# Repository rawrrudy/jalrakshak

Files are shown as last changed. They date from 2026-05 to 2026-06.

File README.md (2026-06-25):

<p align="center">
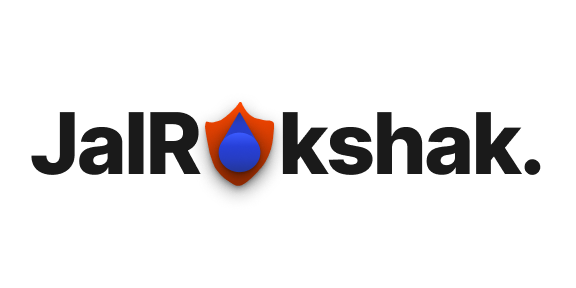
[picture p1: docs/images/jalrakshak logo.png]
  
</p>

<h1 align="center"> JalRakshak </h1>

<p align="center">
  Water Monitoring Device
</p>

<p align="center">
  An ESP-32 powered "floating" water monitoring device with pH, Temperature, TDS and Turbidity sensors!
</p>

# Index

#### [1) JalRakshak Zine](#jalrakshak-zine)
#### [2) What is JalRakshak?](#what-is-jalrakshak)
#### [3) Why was JalRakshak made?](#why-was-jalrakshak-made)
#### [4) Key Features](#key-features)
#### [5) PCB](#pcb)
#### [6) Images](#images)
#### [7) How to Build and Run?](#how-to-build-and-run)
#### [8) Credits](#credits)
#### [9) License](#license)

# JalRakshak Zine

<p align="center">
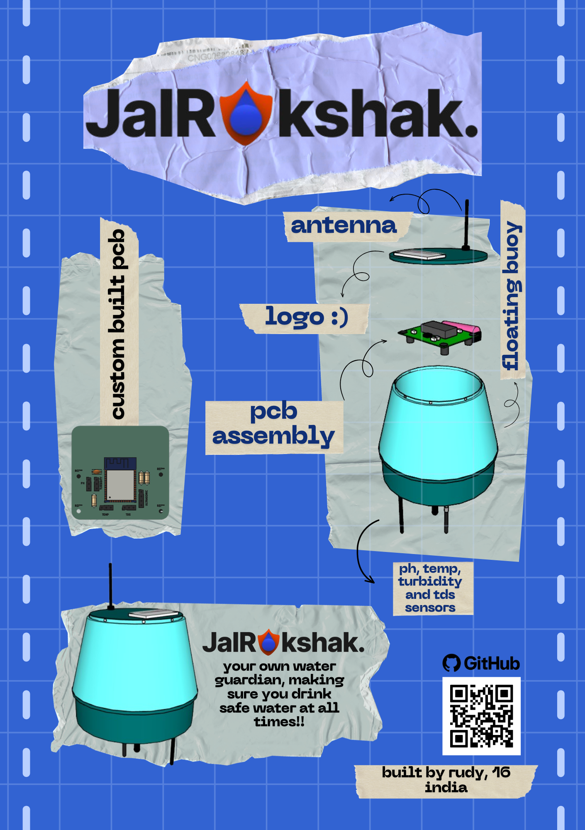
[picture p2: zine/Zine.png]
  
</p>

# What is JalRakshak?

JalRakshak is an ESP32 powered water quality monitoring device, that continously measures pH, TDS, Turbidity, Temperature and Water Level! It uses a custom built PCB and enclosure to help communities protect lakes, reservoirs and local water bodies.

<p align="center"> 
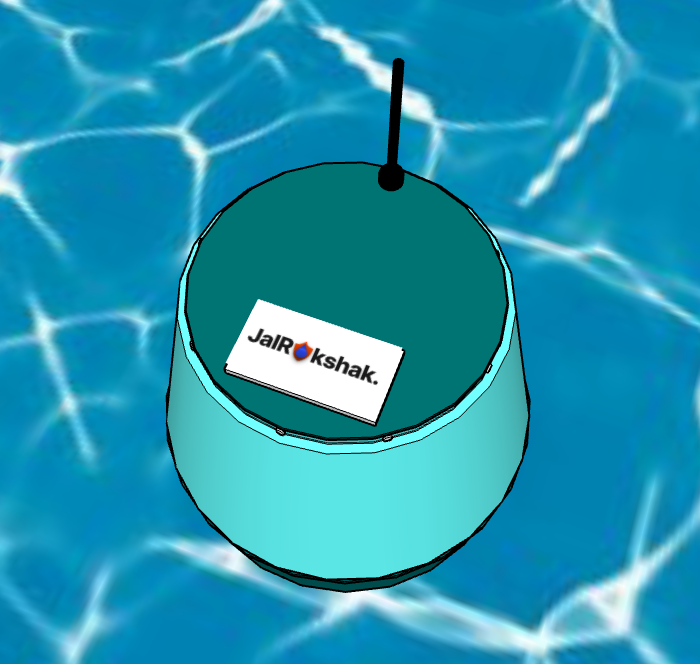
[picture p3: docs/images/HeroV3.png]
   
</p>

<p align="center">
 A basic 3D outline of JalRakshak V1
</p>

# Why was JalRakshak made?

Water pollution is one of the biggest challenges to the environment in recent days. Not only does it affect aquatic fauna, it can also cause significant damage to humans due to unhygenic conditions of water. This issue is widespread in rural areas, especially in the country I am from, India. To help combat this issue, even at a significantly smaller scale, JalRakshak was created. Attached is a link to a credible source which discusses the major problems caused due to water pollution - 

https://www.frontiersin.org/journals/environmental-science/articles/10.3389/fenvs.2022.880246/full

# Key Features

- ESP32 microcontroller with integrated Wi-Fi
- Analyses Temperature, TDS, Turbidity, pH and Water Level
- Sends an alert via email when safety threshold is exceeded
- Custom designed PCB for sensor integration
- DS18B20 waterproof temperature sensor
- DFRobot Gravity pH and TDS sensor
- SEN0189 turbidity sensing for water clarity check
- HC-SR04 ultrasonic water level measurement
- Custom CAD optimised to float on water

# PCB
<p align="center">
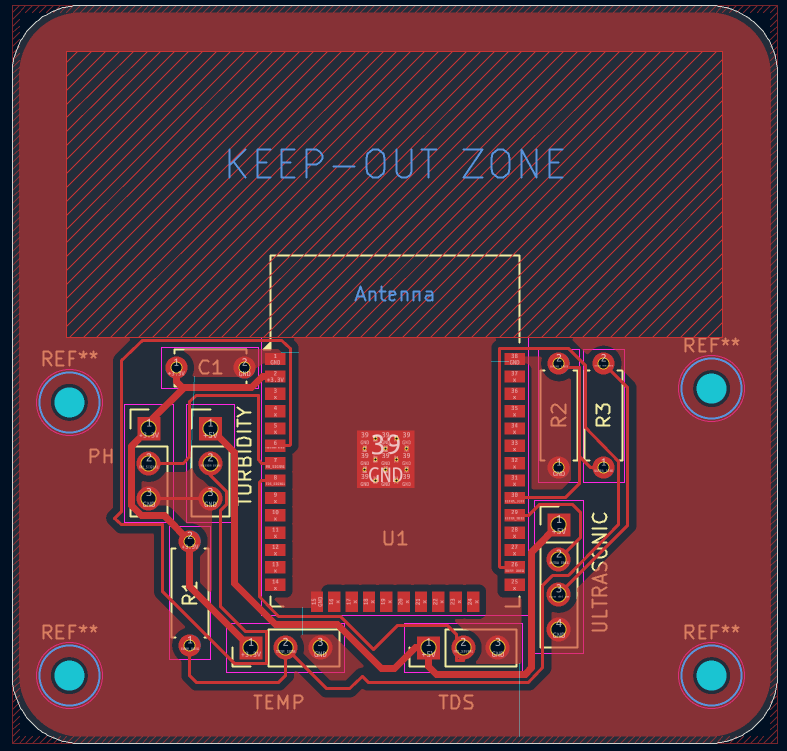
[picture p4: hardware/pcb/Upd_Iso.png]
  
</p>
<p align="center">
  Fig. 1) Top view of the PCB layout for JalRakshak
</p>
<p align="center">
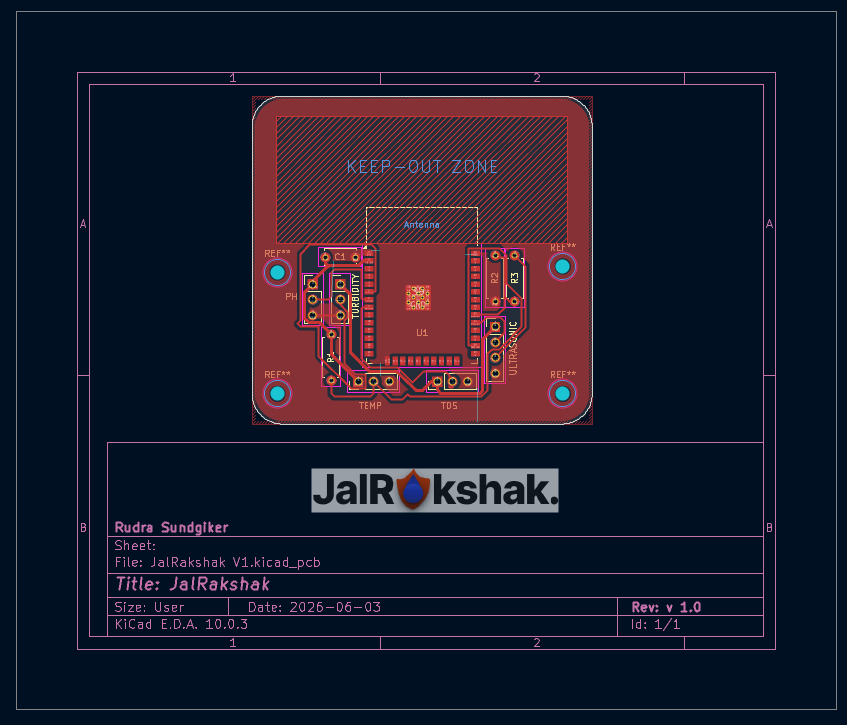
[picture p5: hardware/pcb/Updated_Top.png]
  
</p>
<p align="center">
  Fig. 2) Manufacturing layout of the PCB design
</p>
<p align="center">
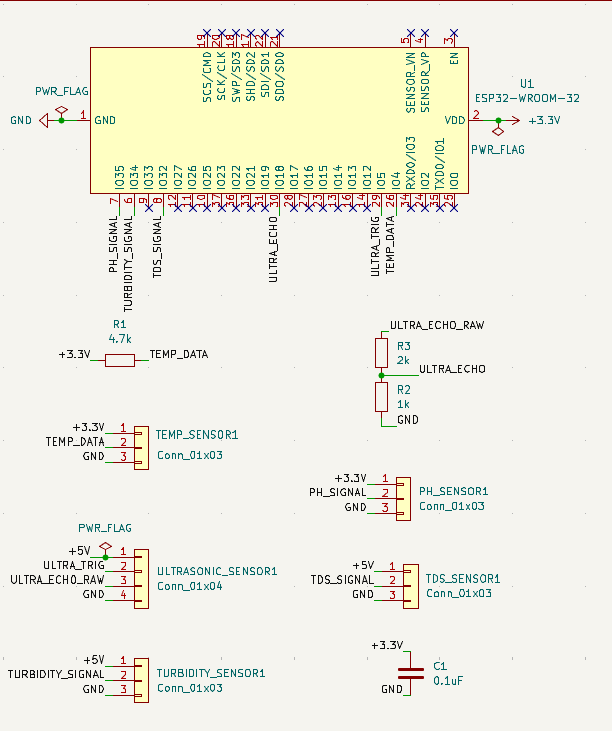
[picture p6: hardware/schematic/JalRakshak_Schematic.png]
  
</p>
<p align="center">
  Fig. 3) Schematic design of JalRakshak
</p>

# Images

<details>
<summary><b> 3D Model</b></summary>

<br>

<p align="center">
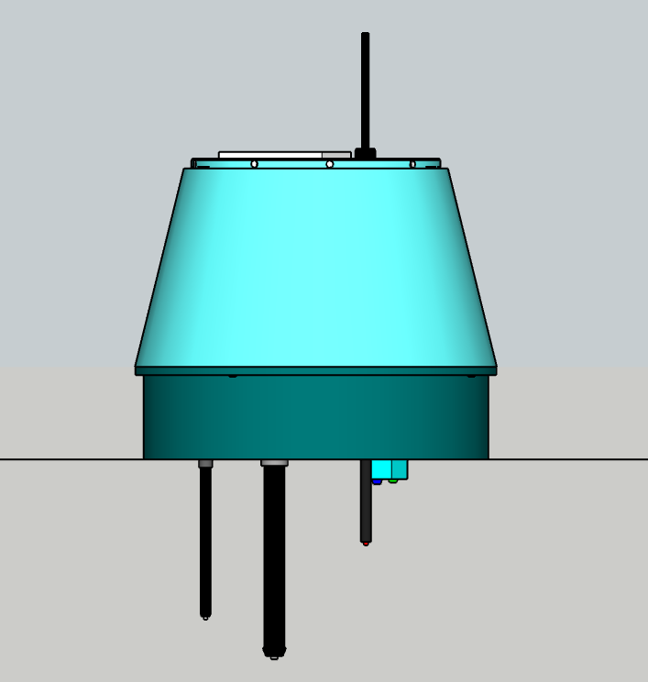
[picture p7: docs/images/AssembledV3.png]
  
  <br>
  <em>Fully assembled JalRakshak enclosure.</em>
</p>

<br>

<p align="center">
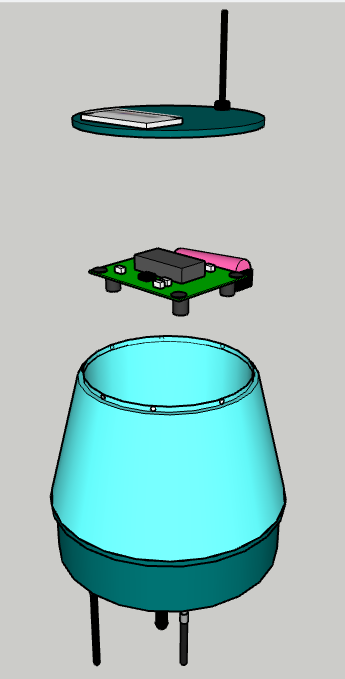
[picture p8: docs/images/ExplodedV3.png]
  
  <br>
  <em>Exploded view showing internal components.</em>
</p>

<br>

<p align="center">
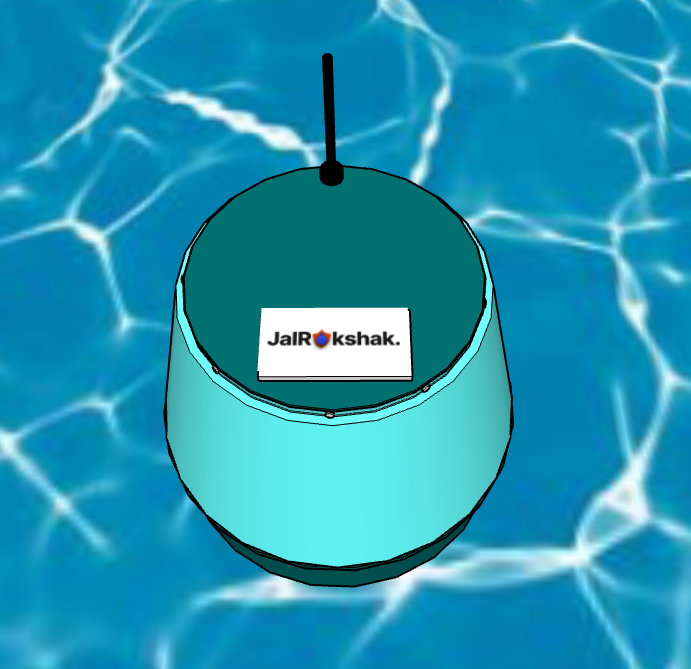
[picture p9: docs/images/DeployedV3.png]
  
  <br>
  <em>Deployed image of a JalRakshak model.</em>
</p>
</details>

<details>
<summary><b> Dashboard </b></summary>

<br>

<p align="center">
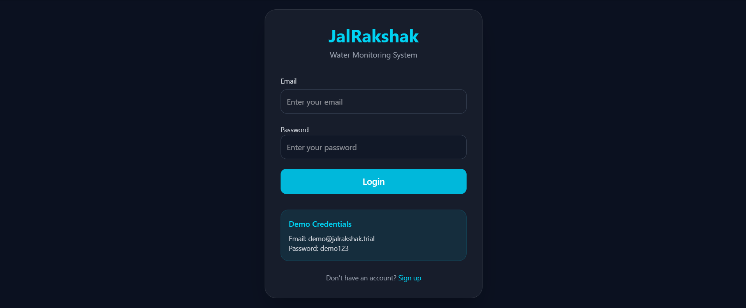
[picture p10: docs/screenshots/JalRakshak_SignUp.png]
  
  <br>
  <em>Sign Up/Login page of JalRakshak.</em>
</p>

<br>

<p align="center">
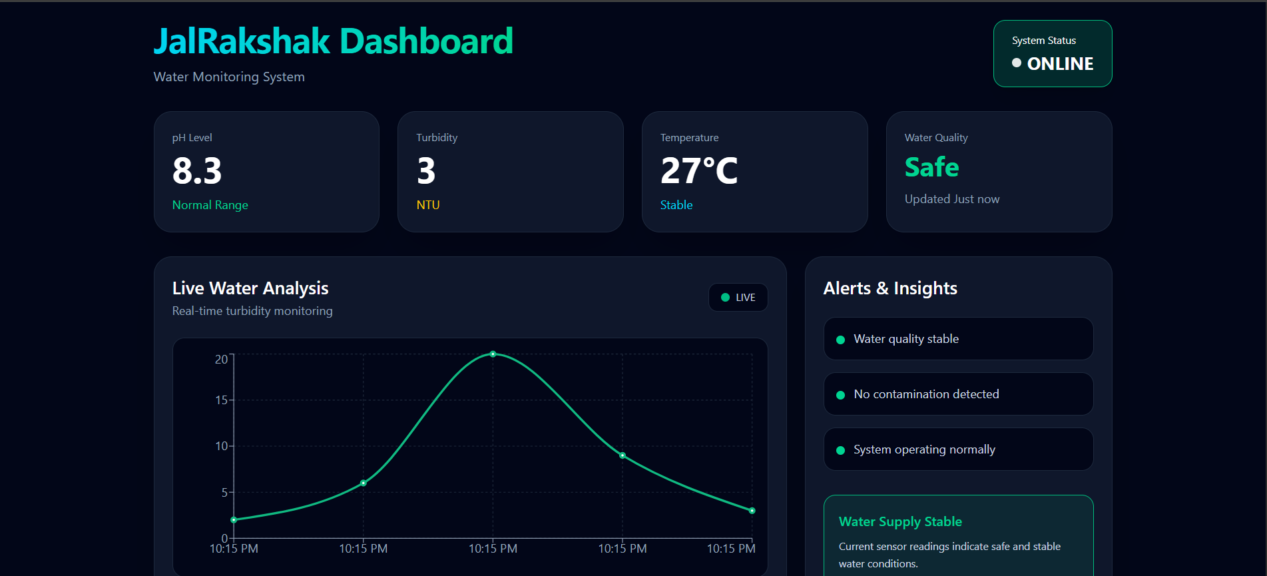
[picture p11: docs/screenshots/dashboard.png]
  
  <br>
  <em>Frontend dashboard of JalRakshak website.</em>
</p>
</details>

<details>
<summary><b>3D PCB Visuals</b></summary>

<br>

<p align="center">
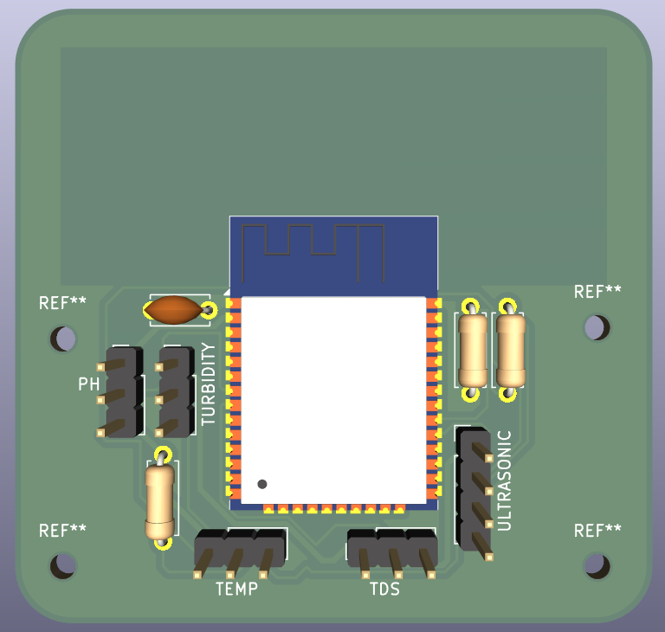
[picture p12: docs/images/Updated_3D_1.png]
  
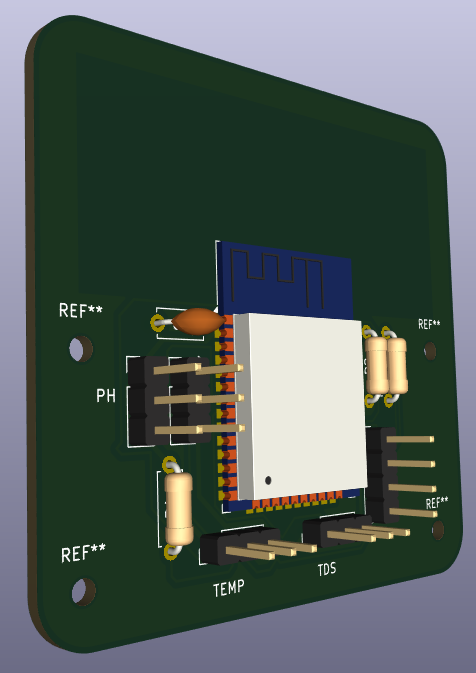
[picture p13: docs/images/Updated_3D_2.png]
  
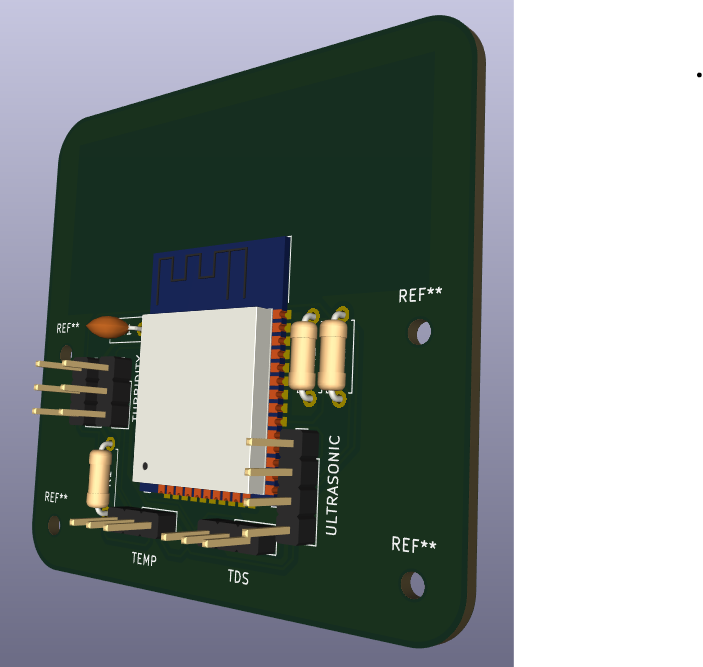
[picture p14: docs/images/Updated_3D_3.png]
  
  <br>
  <em>Visuals of 3D version of PCB.</em>
</p>
</details>

<details>
<summary><b> Other essentials </b></summary>

<br>

<p align="center">
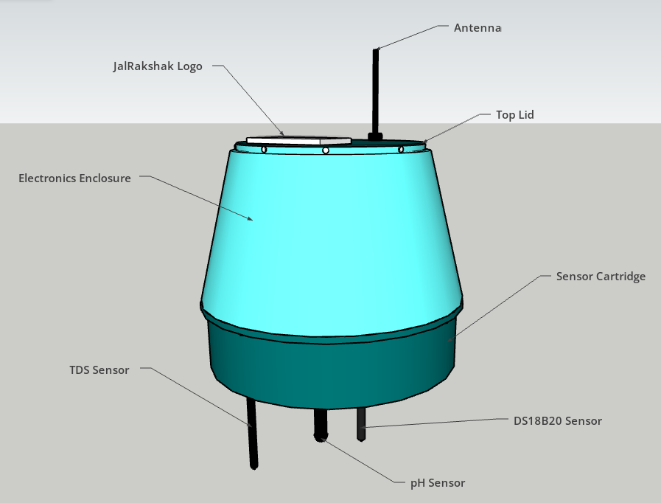
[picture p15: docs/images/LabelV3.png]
  
  <br>
  <em>Fully labelled visual of JalRakshak.</em>
</p>

<p align="center">
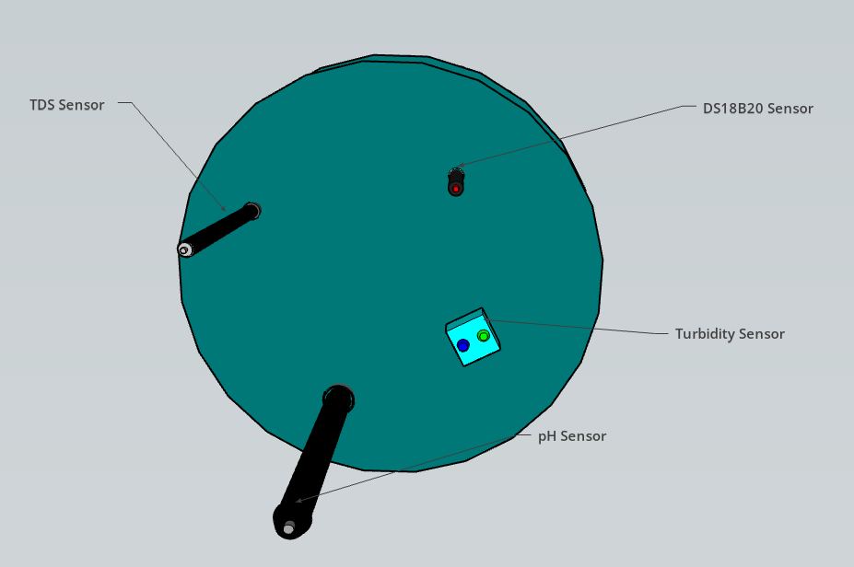
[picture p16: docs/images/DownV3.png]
  
  <br>
  <em>Visuals of all the probes of JalRakshak.</em>
</p>

<p align="center">
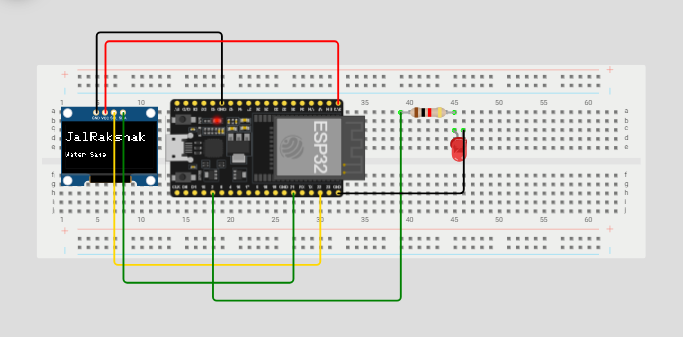
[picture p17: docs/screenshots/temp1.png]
  
  <br>
  <em>Demo prototype of screen of JalRakshak.</em>
</p>
</details>

# How to Build and Run?

>⚠️ Note: At the time of writing, JalRakshak is in the prototype development stage. The assembly and deployment instructions below describe the intended hardware workflow based on the completed PCB, CAD enclosure and firmware design.

Please check the [BOM](BOM.csv) before building this project!

<details>
<summary><b> Hardware </b></summary>

<br>

1. Fabricate or order the JalRakshak PCB using the provided [Gerber](hardware/gerbers) files.
2. Solder the ESP32 and supporting components onto the PCB.
3. Connect the sensors to their designated headers:
   - pH Sensor
   - TDS Sensor
   - Turbidity Sensor
   - DS18B20 Temperature Sensor
   - HC-SR04 Ultrasonic Sensor
4. Mount the PCB inside the enclosure.
5. Route the sensor cables through the enclosure openings.
6. Secure all components and close the enclosure.

</details>

<details>
<summary><b> Firmware Installation </b></summary>

<br>

1. Open the Arduino IDE.
2. Install ESP32 board support through the Board Manager.
3. Install the required libraries:
   - OneWire
   - DallasTemperature
4. Open firmware/jalrakshak_main.ino
5. Upload the firmware to the ESP32.

</details>

<details>
<summary><b> Wiring </b></summary>

<br>

Connect all sensors to the custom JalRakshak PCB according to the schematic available in the repository.

| Component | Connection Type |
|---|---|
| pH Sensor | Analog Input |
| TDS Sensor | Analog Input |
| Turbidity Sensor | Analog Input |
| DS18B20 Temperature Sensor | Digital GPIO |
| HC-SR04 Ultrasonic Sensor | Trigger/Echo GPIO |
| ESP32 | Main Controller |

<p align="center"> 
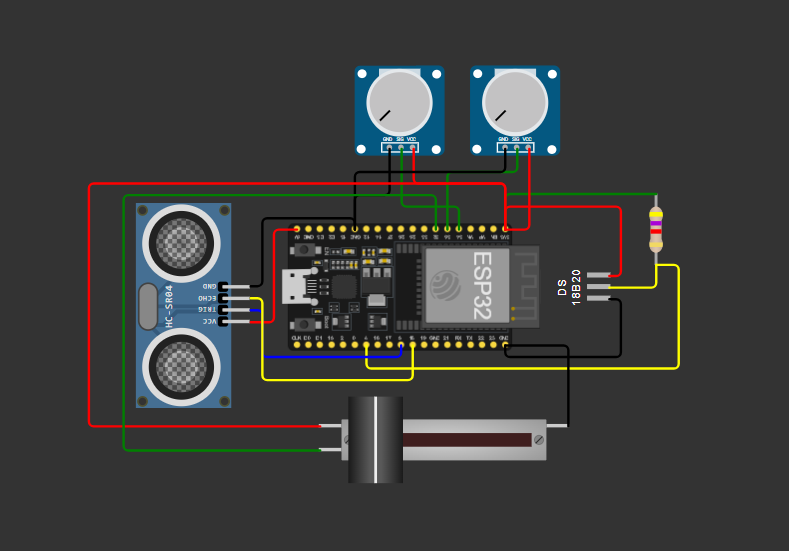
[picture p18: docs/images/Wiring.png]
   
</p>

Refer to the PCB schematic and wiring diagram in the `hardware/pcb` directory for detailed pin mappings.

</details>

<details>
<summary><b> Backend Setup </b></summary>

1. Navigate to the backend directory.
```bash
cd backend
```
2. Create and activate a Python virtual environment.
```bash
python -m venv venv
```
3. Install dependencies.
```bash
pip install -r requirements.txt
```
4. Configure PostgreSQL credentials.
5. Start the FastAPI server.
```bash
uvicorn app.main:app --reload
```

</details>

<details>
<summary><b> Dashboard setup </b></summary>

<br>

1. Navigate to the frontend directory.
```bash
cd frontend
```
2. Install dependencies.
```bash
npm install
```
3. Start the development server.
```bash
npm run dev
```
6. Open the URL displayed in the terminal.
7. Ensure the backend server is running and connected to the database.
8. Verify that live sensor readings are visible on the dashboard.

</details>

<details>
<summary><b> Operation </b></summary>

<br>

1. Power on the device.
2. Place JalRakshak on the water surface.
3. Ensure all sensors are submerged properly.
4. Open the Serial Monitor at 115200 baud.
5. Observe live readings for:
   - pH
   - TDS
   - Temperature
   - Turbidity
   - Water Level
6. Voila! Your very own version of JalRakshak is prepared!
</details>

# Credits

I would like to thank-

[KiCad](https://www.kicad.org/)

[Arduino](https://www.arduino.cc/)

[HackClub Fallout](https://fallout.hackclub.com/)

[SketchUp](https://www.sketchup.com/)

[PostgresSQL](https://www.postgresql.org/)

# License 

This project is licensed under the MIT License. See the [LICENSE](LICENSE) file for more details.

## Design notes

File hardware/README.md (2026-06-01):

# JalRakshak Hardware

## Hardware Components

- ESP32-WROOM-32
- pH Sensor
- DS18B20 Temperature Sensor
- HC-SR04 Ultrasonic Sensor (Water Level Monitoring)
- TDS Sensor
- Turbidity Sensor

## Parameters Monitored

- pH
- Total Dissolved Solids (TDS)
- Turbidity
- Water Level
- Water Temperature

## PCB Design

The PCB was designed using KiCad and integrates all sensors with the ESP32 for real-time data acquisition and transmission.

## Files

- 'JalRakshak V1.kicad_sch' - Schematic
- 'JalRakshak V1.kicad_pcb' - PCB Layout
- 'JalRakshak V1.kicad_pro` - KiCad Project File
- Gerber files for PCB manufacturing

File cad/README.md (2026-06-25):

# CAD Files
Source CAD was created in SketchUp.

- JalRakshak V4.skp (source file)
- JalRakshakExploded V4.skp (source file)
- JalRakshak V4.step
- JalRakshakExploded V4.step

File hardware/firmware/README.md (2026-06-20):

# JalRakshak Firmware

This folder contains the ESP32 firmware for the JalRakshak water monitoring system.

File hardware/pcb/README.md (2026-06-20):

# JalRakshak PCB

This folder contains the PCB design files for JalRakshak.

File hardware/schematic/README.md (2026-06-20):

# JalRakshak Schematic

This folder contains the KiCad schematic files for JalRakshak.

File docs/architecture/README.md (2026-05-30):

# System Architecture

JalRakshak monitors water quality and water levels using multiple sensors connected to an ESP32.

Data Flow:

Sensors → ESP32 → Backend API → Database → Dashboard → Alerts

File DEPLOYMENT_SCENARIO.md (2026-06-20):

# JalRakshak Deployment Scenario

In this section, I explain my overall plans and what I want JalRakshak to do!

## Scenario Overview

This deployment scenario demonstrates how JalRakshak can be implemented in a rural community to continously monitor water quality and water levels in let's say a public water body, used for drinking water, agriculture, and livestock.

### 📍 Location
Example Location: Rural village in Maharashtra, India

### Population Served
Approximately 500 citizens

### Water Source
Community pond used for drinking water, agricultural irrigation, livestock consumption and domestic use.

### Problem Statement
In many rural areas of the world, water is a very scarce and precious resource and not everyone gets adequate access to it. Water contamination often goes undetected until the people start experiencing adverse health effects. Seaonal flooding and declining water levels can also create significant challenges for local communities. 

As a result, communities may not receive timely warnings about unsafe water conditions.

## Proposed JalRakshak Deployment

| Deployment Area | Devices |
|---|---|
| Main Community Pond | 1 |
| Secondary Storage Pond | 1 |
| Irrigation Reservoir | 1 |

Total Devices Required: 3

## Monitoring Parameters

Each JalRakshak unit continously monitors:

- Water Temperature
- Water Level
- pH
- Total Dissolved Solids (TDS)
- Turbidity

Sensor readings are transmitted to the JalRakshak backend through WiFi connectivity.

## Data Flow

Sensors ⟶ ESP32 Controller ⟶ WiFi Network ⟶ JalRakshak Backend ⟶ PostgreSQL Database ⟶ Monitoring Dashboard ⟶ Email Alerts

## Alert Scenarios

### Unsafe Water Quality

If any sensor detects values outside safe limits, for example:

- Unsafe pH levels
- Excessive turbidity
- Elevated TDS Levels

The system immediately generates an alert and notifies responsible stakeholders through email.

### Flood Risk

If water levels rise beyond predefined thresholds:

- Flood warnings are generated
- Authorities can take preventive action

### Low Water Levels

If water levels fall below critical levels:

- Water conservation measures can be initiated
- Resource planning becomes easier.

## Expected benefits

### Public Health

Consumption of contaminated and unsafe water can be extremely harmful, and can sometimes also lead to death. JalRakshak tries and prevents such tragedies from occuring by continously monitoring and updating the quality of a particular water source hence keeping the consumers safe from potential adverse health effects.

### Resource Management

JalRakshak also contributes massively into managing our existing resources tactfully and sustainably by better monitoring during monsoon and summer seasons, and improving planning during drought conditions.

## Estimated Annual Impact

For a village of approximately 500 residents,

- Continous monitoring of critical water sources
- Immediate detection of unsafe water conditions
- Improved awareness of water quality trends
- Faster response to contamination and flooding events

## Conclusion

At the beginning, this project felt like a huge deal but gradyally I enjoyed the process of bringing JalRakshak to life. It illustrates how even low cost IoT technology can provide continous water monitoring for rural communities, potentially saving people from suffering from adverse diseases and in some cases, saving lives.

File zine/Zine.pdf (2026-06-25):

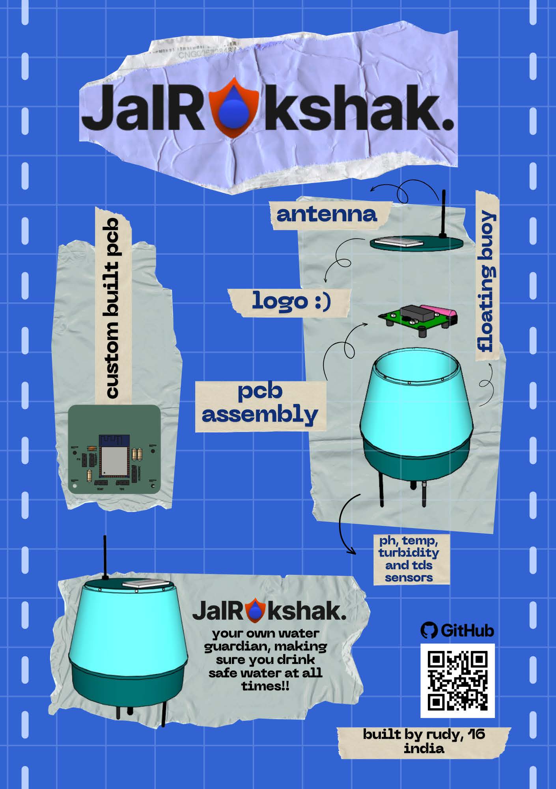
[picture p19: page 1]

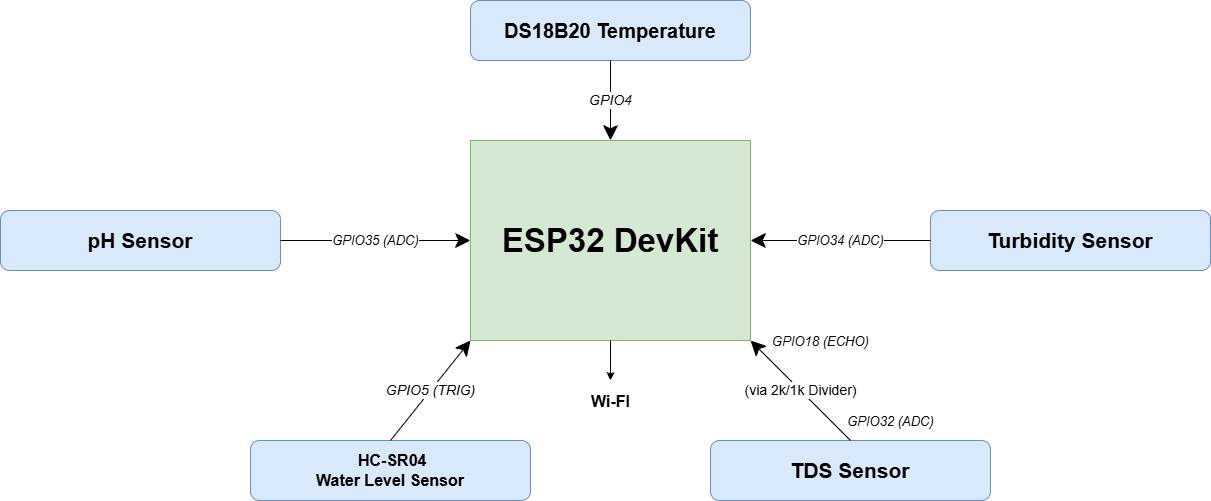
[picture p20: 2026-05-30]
docs/architecture/hardware_architecture.drawio.png

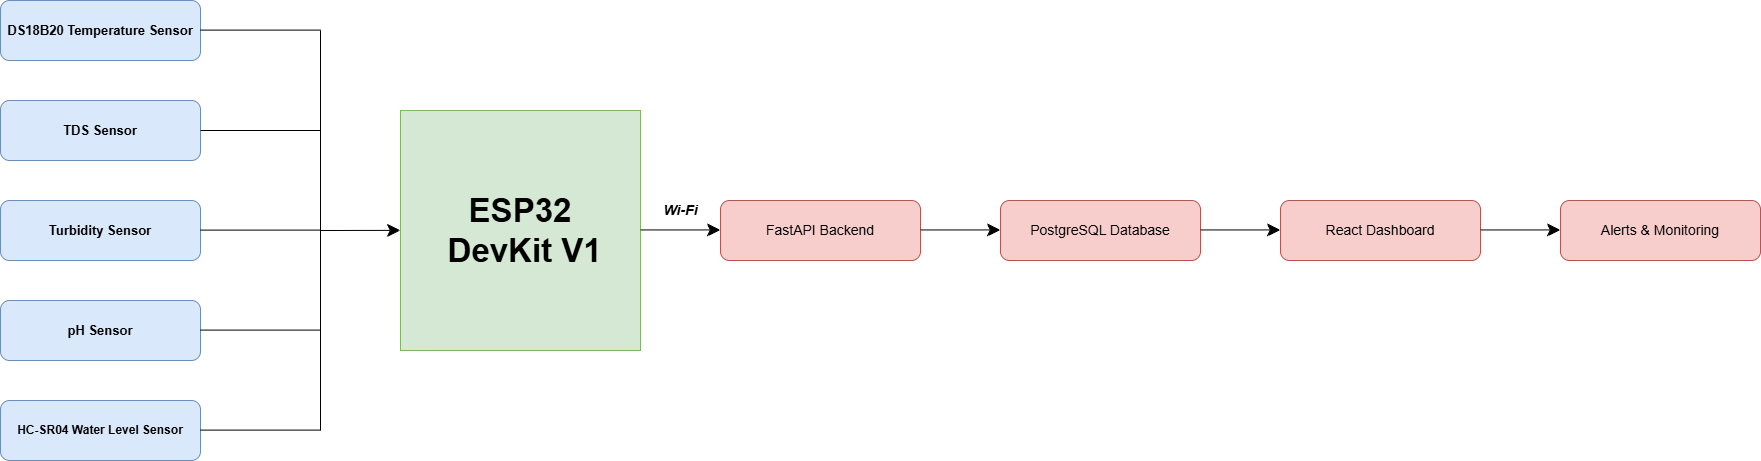
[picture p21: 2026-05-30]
docs/architecture/system_architecture.drawio.png

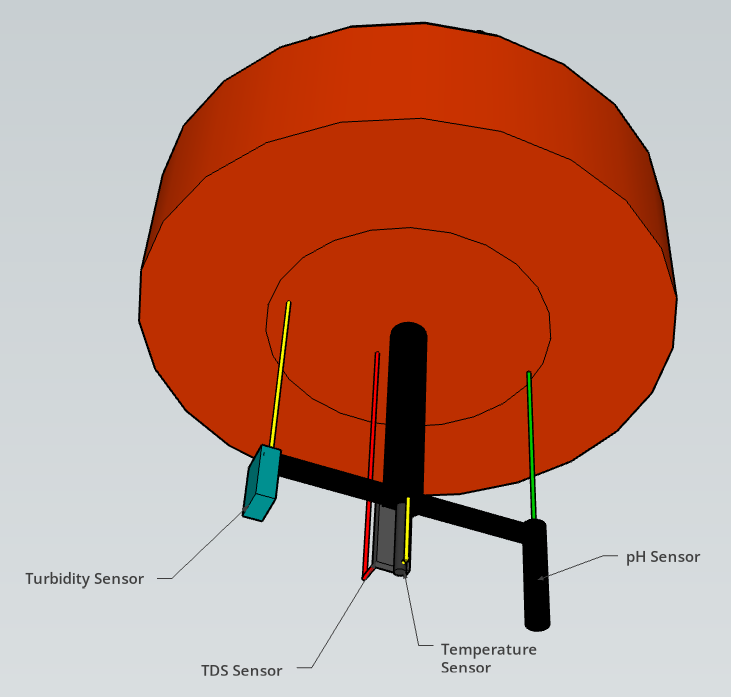
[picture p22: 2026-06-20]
docs/images/JR-Down.png

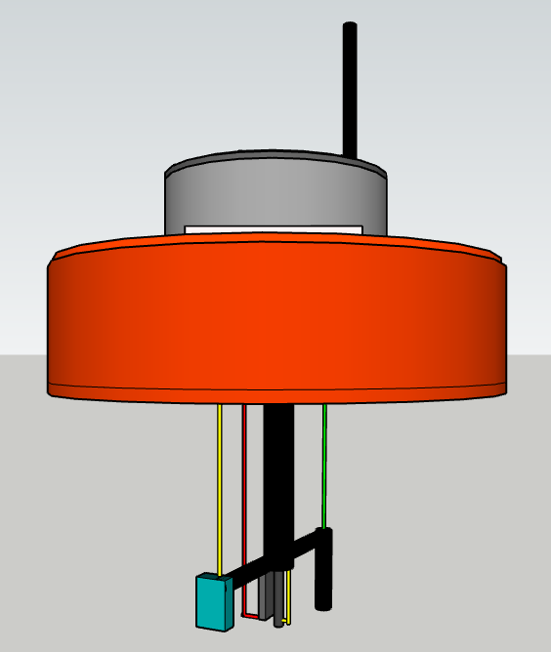
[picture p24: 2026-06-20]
docs/images/JR-05.png

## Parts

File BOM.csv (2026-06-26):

Component | Model | Quantity | Product Link | Total Cost
ESP-32-WROOM-32 | RoboticsDNA ESP32 WROOM-32 | 1 | https://roboticsdna.in/product/esp32-wroom-32-c-type-cp2102-usb-dual-core-wifi-bluetooth-38-pins-model-2/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 | $6
HC-SR04 Ultrasonic Sensor | Robocraze HC-SR04 Ultrasonic Sensor | 1 | https://www.amazon.in/dp/B01I1ZTPJC?ref=ppx_yo2ov_dt_b_fed_asin_title | $2.20
DS18B20 Waterproof Sensor | Robodo SEN9 DS18B20 | 1 | https://www.amazon.in/dp/B073Q3D7YQ?ref=ppx_yo2ov_dt_b_fed_asin_title | $2.08
TDS Sensor | DFRobot Gravity Analog TDS Water Sensor | 1 | https://www.amazon.in/dp/B0GGBRGK55?ref=ppx_yo2ov_dt_b_fed_asin_title | $20.39
Turbidity Sensor | Robocraze Turbidity Detection Sensor | 1 | https://www.amazon.in/dp/B08MW2QHCD?ref=ppx_yo2ov_dt_b_fed_asin_title&th=1 | $8.78
pH Sensor | LABART 0-14 pH Probe | 1 | https://www.amazon.in/dp/B0CLDH25VK?ref=ppx_yo2ov_dt_b_fed_asin_title | $4.18
4.7k Resistor | Electronic Spices 4.7K Ohm (Ω) Resistors | 1 | https://www.amazon.in/Electronic-Spices-Tolerance-Through-Resistors/dp/B0BDTXKCM3 | $0.02
2k Resistor | Electronic Spices 2.2K Ohm (Ω) Resistors | 1 | https://www.amazon.in/Electronic-Spices-Tolerance-Through-Resistors/dp/B0BDTXKCM3 | $0.02
1k Resistor | Electronic Spices 1K Ohm (Ω) Resistors | 1 | https://www.amazon.in/Electronic-Spices-Tolerance-Through-Resistors/dp/B0BF4ZY1KV | $0.07
0.1µF Capacitor | AVS COMPONENTS 0.1µF Capacitor | 1 | https://www.amazon.in/AVS-COMPONENTS-Ceramic-Capacitor-50pcs/dp/B08THNHHHX | $0.02
Headers/Connectors | - | 5 | - | -
- | - | - | - | $43.76

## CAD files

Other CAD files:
cad/JalRakshak V4.skp
cad/JalRakshakExploded V4.skp

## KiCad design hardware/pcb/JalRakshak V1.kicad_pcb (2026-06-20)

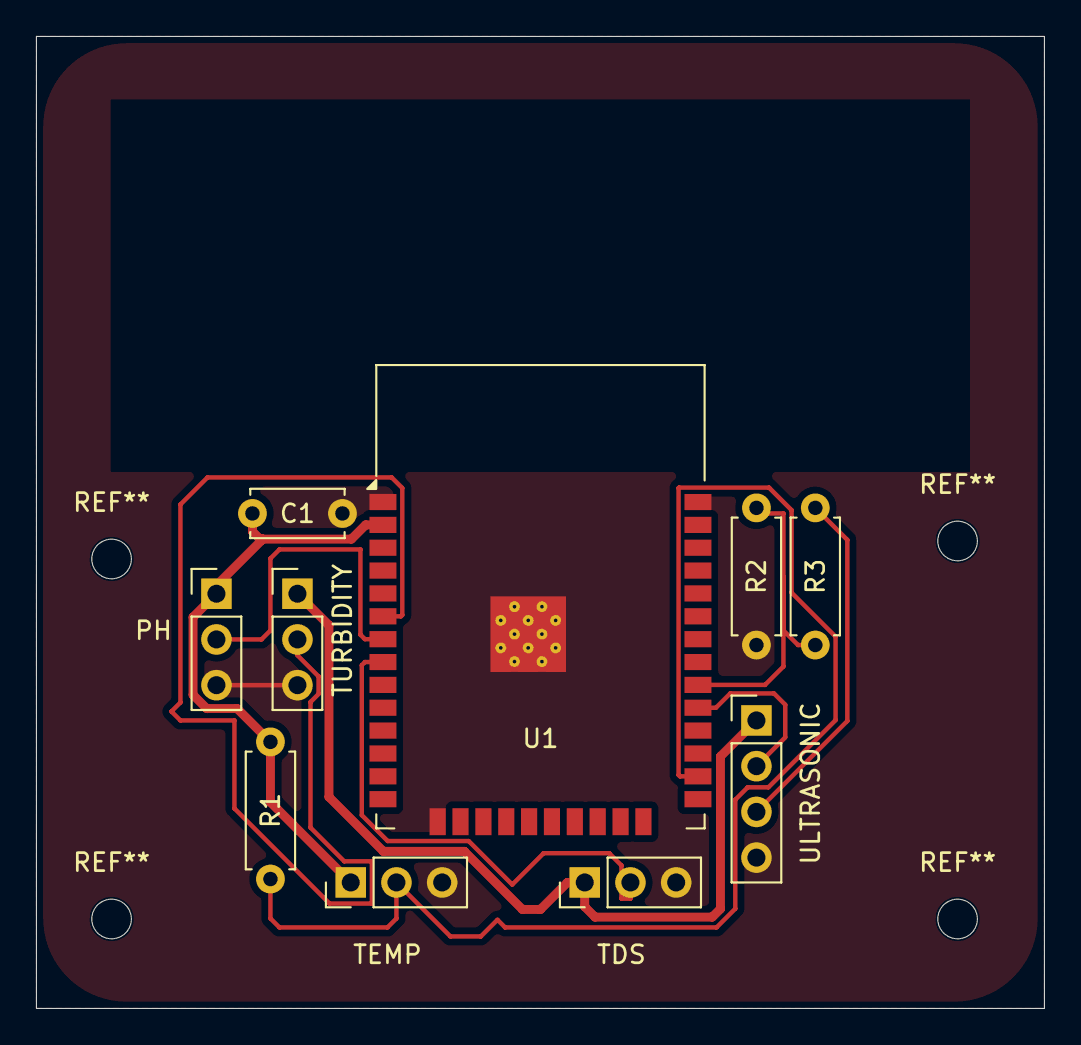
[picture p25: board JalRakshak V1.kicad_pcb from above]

Board: 2 copper layers, 56.0 x 54.0 mm, 10 parts (0 on the bottom side), 10 nets.

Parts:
C1: 0.1uF; C_Disc_D5.0mm_W2.5mm_P5.00mm
PH: Conn_01x03; PinHeader_1x03_P2.54mm_Vertical
R1: 4.7k; R_Axial_DIN0207_L6.3mm_D2.5mm_P7.62mm_Horizontal
R2: 1k; R_Axial_DIN0207_L6.3mm_D2.5mm_P7.62mm_Horizontal
R3: 2k; R_Axial_DIN0207_L6.3mm_D2.5mm_P7.62mm_Horizontal
TDS: Conn_01x03; PinHeader_1x03_P2.54mm_Vertical
TEMP: Conn_01x03; PinHeader_1x03_P2.54mm_Vertical
TURBIDITY: Conn_01x03; PinHeader_1x03_P2.54mm_Vertical
U1: ESP32-WROOM-32
ULTRASONIC: Conn_01x04; PinHeader_1x04_P2.54mm_Vertical

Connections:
+3.3V: C1.1, PH.1, R1.2, TEMP.1, U1.2 (VDD)
/+5V: TDS.1, TURBIDITY.1, ULTRASONIC.1
/PH_SIGNAL: PH.2, U1.7 (IO35)
/TDS_SIGNAL: TDS.2, U1.8 (IO32)
/TEMP_DATA: R1.1, TEMP.2, U1.26 (IO4)
/TURBIDITY_SIGNAL: TURBIDITY.2, U1.6 (IO34)
/ULTRA_ECHO: R2.2, R3.1, U1.30 (IO18)
/ULTRA_ECHO_RAW: R3.2, ULTRASONIC.3
/ULTRA_TRIG: U1.29 (IO5), ULTRASONIC.2
GND: C1.2, PH.3, R2.1, TDS.3, TEMP.3, TURBIDITY.3, U1.1 (GND), U1.15 (GND), U1.38 (GND), U1.39 (GND), ULTRASONIC.4

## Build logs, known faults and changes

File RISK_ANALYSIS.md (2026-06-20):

# JalRakshak Risk and Failure Analysis

I have created this document to identify any potential failure that may occur during the deployment of JalRakshak. Alongside this, I have also added mitigation techniques to improve system reliability and safety.

The objective is to ensure continous monitoring of water bodies while minimizing the downtime, inaccurate readings, and potential hardware failures.

## Failure Mode Assessment

| Failure Mode | Cause | Impact | Severity | Mitigation Strategy |
|---|---|---|---|---|
| pH Sensor Drift | Long term use and contamination | Incorrect pH readings | Medium | Periodic calibration and maintenance |
| TDS Sensor Fouling | Mineral buildup on probe | Inaccurate water quality measurements | Medium | Regular cleaning schedule |
| Turbidity Sensor Obstruction | Mud, algae, or debris accumulation | False turbidity readings | Medium | Protective housing and periodic inspection |
| Ultrasonic Sensor Obstruction | Waves or uneven water surface | Incorrect water level readings | Low | Multiple readings and averaging algorithm |
| ESP32 Failure | Hardware malfunction or overheating | Complete system outage | Very High | Modular design allowing rapid replacement |
| Battery Depletion | Long term operation without charging | Device shutdown | High | Battery monitoring and low power alerts |
| WiFi Connectivity Loss | Weak signal or network outage | Data upload interruption | Medium | Local data buffering and automatic reconnection |
| PCB Water Ingress | Enclosure Leakage | Short circuit and hardware damage | High | Waterproof enclosure and sealing gaskets |
| Corrosion of Components | Continous exposure to moisture | Reduced hardware lifespan | Medium | Corrosion resistant materials and coatings |
| Backend Server Downtime | Hosting or infrastructure issues | Dashboard unavailable | Medium | Cloud deployment and periodic backups |

## Reliability  Measures Implemented

The following reliability measures have already been incorporated into JalRakshak!

- Automatic email alerts for unsafe water conditions
- Battery level monitoring
- Modular PCB architecture
- Cloud based backend for centralised monitoring
- Continous sensor data collection
- Status classification into Safe, Warning and Danger

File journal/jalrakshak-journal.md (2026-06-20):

# JalRakshak — Journal Export

- Exported at: 2026-05-27T17:53:28Z
- Project ID: 3732
- Entries: 8

## Entry 1
- ID: 8733
- Author: rudrasundgikar
- Created At: 2026-05-23T20:56:43Z

### Content

I successfully developed the foundational backend infrastructure for the JalRakshak project using FastAPI and PostgreSQL. I created the complete project structure, configured the Python virtual environment, installed all necessary dependencies, and built a working API server. I also connected the backend to a PostgreSQL database using SQLAlchemy and created functional GET and POST APIs capable of storing and retrieving sensor data. After debugging multiple issues related to imports, localhost networking, database configuration, and port conflicts, I successfully tested all endpoints through FastAPI Swagger Docs.
Screenshot 2026-05-24 022419.png

### Recording Links

- https://lookout.hackclub.com/api/media/00466889-dfeb-411a-9b4a-b566bb477e06/video.mp4

## Entry 2
- ID: 8847
- Author: rudrasundgikar
- Created At: 2026-05-24T11:30:53Z

### Content

I initialized the JalRakshak frontend using React and Vite, configured Tailwind CSS, and built the first version of the dashboard UI. The dashboard now includes live monitoring cards, alert panels, sensor status sections, and a futuristic responsive design for the water monitoring system.
Screenshot 2026-05-24 170018.png

### Recording Links

- https://lookout.hackclub.com/api/media/174c7445-cb16-44a3-92b6-78f3ff929410/video.mp4

## Entry 3
- ID: 9066
- Author: rudrasundgikar
- Created At: 2026-05-25T08:37:45Z

### Content

I refined the JalRakshak frontend architecture by configuring the development environment, organizing the project structure, and implementing interactive dashboard components. I also worked on improving the visual layout, responsiveness, and real-time monitoring interface for future sensor integration. Hope this project plans out to be super duper amazing!!!!!


### Recording Links

- https://lookout.hackclub.com/api/media/2b181433-3625-4ee1-9a06-d6bfc202d005/video.mp4

## Entry 4
- ID: 9180
- Author: rudrasundgikar
- Created At: 2026-05-25T19:16:30Z

### Content

Today, I finally started working on the structural part of JalRakshak. This was my first time using "Wokwi" and that DEFINITELY caused a lot of problems. But I managed to correct it at the end of the day!!!! This is a basic prototype of what JalRakshak will look like.
wokwi 1.png

### Recording Links

- https://lookout.hackclub.com/api/media/ccc8e8f4-b837-4ce2-b5f4-32a52045811d/video.mp4

## Entry 5
- ID: 9409
- Author: rudrasundgikar
- Created At: 2026-05-26T16:46:40Z

### Content

So today I worked and polished the UI layout of JalRakshak!!!! I added demo data and graphs to the dashboard. When I calibrate real time data to the backend, I will test this site once again. 


### Recording Links

- https://lookout.hackclub.com/api/media/3e6d1fc8-3a15-4bb8-bd2b-7b3903cc7925/video.mp4

## Entry 6
- ID: 9610
- Author: rudrasundgikar
- Created At: 2026-05-27T08:56:44Z

### Content

Worked on the backend for some time and also added email alerts when water quality seems to be derailed. 


### Recording Links

- https://lookout.hackclub.com/api/media/736a22e5-d9ab-4738-b476-23417c7aa389/video.mp4
- https://lookout.hackclub.com/api/media/bce38c93-b4c1-49dc-aa96-00d080a9936d/video.mp4

## Entry 7
- ID: 9614
- Author: rudrasundgikar
- Created At: 2026-05-27T09:35:36Z

### Content

Integrated the backend with the frontend!! This project is so close to being turned out good!!! The Swagger docs showed no issues in the code!!!


### Recording Links

- https://public.lapse-hackclub.link/timelapses/Xr7i0-twYzXv/timelapse-Xr7i0-twYzXv.mp4

## Entry 8
- ID: 9650
- Author: rudrasundgikar
- Created At: 2026-05-27T13:24:08Z

### Content

So today I worked on the schematic diagram of the PCB. I am quite new to KiCad as a whole, but I think it will turn out to be pretty good!


### Recording Links

- https://public.lapse-hackclub.link/timelapses/rPHVxlkfcDvJ/timelapse-rPHVxlkfcDvJ.mp4

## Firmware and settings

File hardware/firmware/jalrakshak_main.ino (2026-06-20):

#include <OneWire.h>
#include <DallasTemperature.h>

//----------------PINS---------------------
#define ONE_WIRE_BUS 4

#define PH_PIN 34
#define TDS_PIN 35
#define TURBIDITY_PIN 32

#define TRIG_PIN 5
#define ECHO_PIN 18

//----------------TEMP SENSOR----------------
OneWire oneWire(ONE_WIRE_BUS);
DallasTemperature tempSensor(&oneWire);

void setup() {
  Serial.begin(115200);

  tempSensor.begin();

  pinMode(TRIG_PIN, OUTPUT);
  pinMode(ECHO_PIN, INPUT);

  Serial.println("JalRakshak Sensors Started");
}

void loop() {

  //===================TEMPERATURE==================
  tempSensor.requestTemperatures();
  float temperature = tempSensor.getTempCByIndex(0);

  //====================PH==========================
  int phADC = analogRead(PH_PIN);
  float phVoltage = phADC * (3.3 / 4095.0);

  // Placeholder calibration
  float pH = 7 + ((2.5 - phVoltage) / 0.18);

  //====================TDS==========================
  int tdsADC = analogRead(TDS_PIN);
  float tdsVoltage = tdsADC * (3.3 / 4095.0);

  float tds = 
      (133.42 * tdsVoltage * tdsVoltage * tdsVoltage
      -255.86 * tdsVoltage * tdsVoltage
      +857.39 * tdsVoltage) * 0.5;

  // ==================TURBIDITY=====================
  int turbidityADC = analogRead(TURBIDITY_PIN);
  float turbidityVoltage = turbidityADC * (3.3 / 4095.0);

  float ntu =
      -1120.4 * turbidityVoltage * turbidityVoltage
      +5742.3 * turbidityVoltage
      -4352.9;

  if (ntu < 0) ntu = 0;

  // ==================ULTRASONIC====================
  digitalWrite(TRIG_PIN, LOW);
  delayMicroseconds(2);

  digitalWrite(TRIG_PIN, HIGH);
  delayMicroseconds(10);

  digitalWrite(TRIG_PIN, LOW);

  long duration = pulseIn(ECHO_PIN, HIGH);

  float distance =
      duration * 0.0343 / 2.0;

  // ===================OUTPUT========================
  Serial.println("================================");

  Serial.print("Temperature: ");
  Serial.print(temperature);
  Serial.println(" C");

  Serial.print("pH: ");
  Serial.println(pH, 2);

  Serial.print("TDS: ");
  Serial.print(tds);
  Serial.println(" ppm");

  Serial.print("Turbidity: ");
  Serial.print(ntu);
  Serial.println(" ppm");

  Serial.print("Water Level Distance: ");
  Serial.print(distance);
  Serial.println(" cm");

  Serial.println("================================");
  Serial.println();

  delay(2000);
}

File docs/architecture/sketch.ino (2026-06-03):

#include <Wire.h>
#include <Adafruit_GFX.h>
#include <Adafruit_SSD1306.h>

#define SCREEN_WIDTH 128
#define SCREEN_HEIGHT 64

// OLED display object
Adafruit_SSD1306 display(SCREEN_WIDTH, SCREEN_HEIGHT, &Wire, -1);

// LED pin
const int ledPin = 2;

void setup() {

  // Start LED pin
  pinMode(ledPin, OUTPUT);

  // Start I2C communication
  Wire.begin(21, 22);

  // Start OLED
  if(!display.begin(SSD1306_SWITCHCAPVCC, 0x3C)) {
    while(true);
  }

  // Clear OLED
  display.clearDisplay();

  // Big title text
  display.setTextSize(2);
  display.setTextColor(SSD1306_WHITE);

  // First line
  display.setCursor(0, 10);
  display.println("JalRakshak");

  // Smaller text
  display.setTextSize(1);

  // Second line
  display.setCursor(0, 40);
  display.println("Water Safe");

  // Show everything on screen
  display.display();
}

void loop() {

  // Blink LED ON
  digitalWrite(ledPin, HIGH);
  delay(1000);

  // Blink LED OFF
  digitalWrite(ledPin, LOW);
  delay(1000);
}

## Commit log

2026-05-30 Create .gitkeep schematic
2026-05-30 Create .gitkeep pcb
